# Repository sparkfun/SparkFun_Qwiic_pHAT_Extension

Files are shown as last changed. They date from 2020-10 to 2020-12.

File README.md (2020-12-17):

SparkFun Raspberry Pi 400 Qwiic pHAT Extension
========================================

SparkFun Raspberry Pi 400 Qwiic pHAT Extension (https://www.sparkfun.com/products/17512)

[*SparkFun Raspberry Pi 400 Qwiic pHAT Extension (DEV-17512)*](https://www.sparkfun.com/products/17512)

The SparkFun Qwiic pHAT Extension for the Raspberry Pi 400 provides you with a quick and easy solution to access all of the 400's GPIO, stack your favorite HAT right-side up, or connect a Qwiic-enabled device to the I<sup>2</sup>C bus (GND, 3.3V, SDA, and SCL). Since the Qwiic system allows for daisy-chaining boards with different addresses, you can also stack as many sensors as you’d like to the mounting holes on the pHAT to create a tower of sensing power! 

The Qwiic pHAT Extension connects to the Raspberry Pi 400's GPIO using a 2x20 right angle header and extends out to the edge of the PCB. Two Qwiic connectors are included on each side of the board for easy access to the I<sup>2</sup>C bus. A set of large silicone bumpers have also been included for better stability when connecting the Qwiic pHAT Extension to the Raspberry Pi 400's GPIO port. 

Repository Contents
-------------------

* **/Hardware** - Eagle design files (.brd, .sch)
* **/Production** - Production panel files (.brd)

Documentation
--------------
* **[Qwiic Py](https://github.com/sparkfun/Qwiic_Py)** - Python packages for Qwiic-enabled devices
* **[Hookup Guide](https://learn.sparkfun.com/tutorials/raspberry-pi-400-qwiic-phat-extension-hookup-guide)** - Basic hookup guide

Product Versions
----------------
* [DEV-17512](https://www.sparkfun.com/products/17512)

Version History
---------------
* [v1.0](https://github.com/sparkfun/SparkFun_Qwiic_pHAT_Extension/tree/v1.0) - Initial Release

License Information
-------------------

This product is _**open source**_! 

Please review the LICENSE.md file for license information. 

If you have any questions or concerns on licensing, please contact technical support on our [SparkFun forums](https://forum.sparkfun.com/viewforum.php?f=152).

Distributed as-is; no warranty is given.

- Your friends at SparkFun.

_<COLLABORATION CREDIT>_

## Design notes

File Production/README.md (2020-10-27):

SparkFun <PRODUCT NAME> Production Files
=========================================

These are the production files SparkFun uses for printing PCBs.

License Information
-------------------
This product is open source! 

The hardware is released under [Creative Commons ShareAlike 4.0 International](https://creativecommons.org/licenses/by-sa/4.0/).

Please use, reuse, and modify these files as you see fit. Please maintain attribution to SparkFun Electronics and release anything derivative under the same license.

Distributed as-is; no warranty is given.

- Your friends at SparkFun.

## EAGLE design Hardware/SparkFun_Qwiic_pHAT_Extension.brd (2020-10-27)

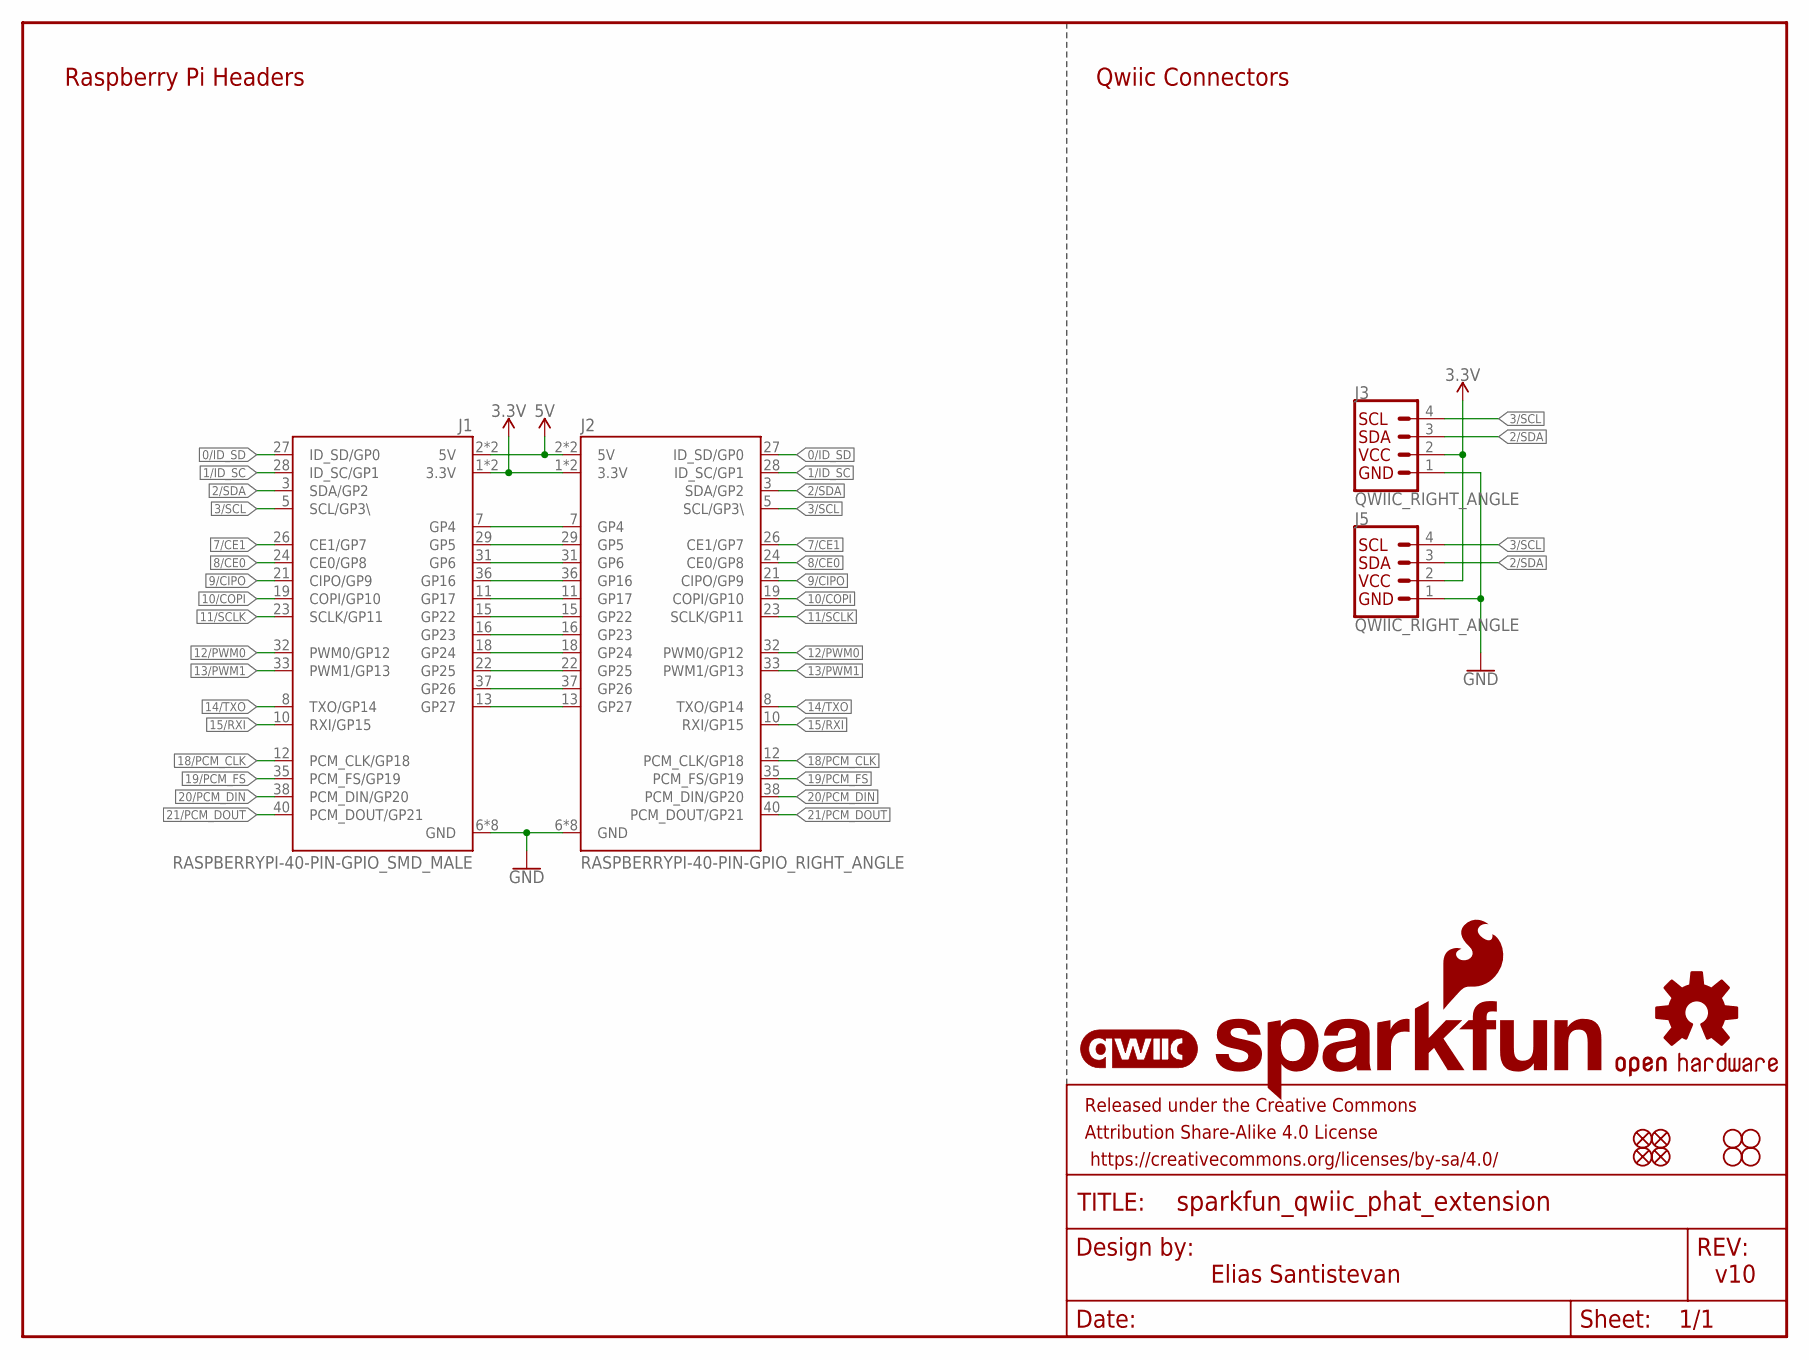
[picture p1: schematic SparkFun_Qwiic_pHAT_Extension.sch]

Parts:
FD1, FD2, FD3, FD4: FIDUCIALUFIDUCIAL; FIDUCIAL-MICRO
FRAME1: FRAME-LETTER; CREATIVE_COMMONS
H1, H2, H3, H4: STAND-OFFTIGHT; STAND-OFF-TIGHT
J1: RASPBERRYPI-40-PIN-GPIO_SMD_MALE; RASPBERRY_PI_HAT_40_PIN_SMD_MALE
J2: RASPBERRYPI-40-PIN-GPIO_RIGHT_ANGLE; 2X20_RIGHT_ANGLE
J3, J5: QWIIC_RIGHT_ANGLE; JST04_1MM_RA
LOGO1: QWIIC_LOGO_5MM; QWIIC_5MM
LOGO2: SFE_LOGO_NAME_FLAME.2_INCH; SFE_LOGO_NAME_FLAME_.2
LOGO3: OSHW-LOGOM; OSHW-LOGO-M

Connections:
0/ID_SD: J1.27 (ID_SD/GP0), J2.27 (ID_SD/GP0)
1/ID_SC: J1.28 (ID_SC/GP1), J2.28 (ID_SC/GP1)
2/SDA: J1.3 (SDA/GP2), J2.3 (SDA/GP2), J3.3, J5.3
3.3V: J1.1 (3.3V), J1.17 (3.3V), J2.1 (3.3V), J2.17 (3.3V), J3.2, J5.2
3/SCL: J1.5 (SCL/GP3\), J2.5 (SCL/GP3\), J3.4, J5.4
5V: J1.2 (5V), J1.4 (5V), J2.2 (5V), J2.4 (5V)
7/CE1: J1.26 (CE1/GP7), J2.26 (CE1/GP7)
8/CE0: J1.24 (CE0/GP8), J2.24 (CE0/GP8)
9/CIPO: J1.21 (CIPO/GP9), J2.21 (CIPO/GP9)
10/COPI: J1.19 (COPI/GP10), J2.19 (COPI/GP10)
11/SCLK: J1.23 (SCLK/GP11), J2.23 (SCLK/GP11)
12/PWM0: J1.32 (PWM0/GP12), J2.32 (PWM0/GP12)
13/PWM1: J1.33 (PWM1/GP13), J2.33 (PWM1/GP13)
14/TXO: J1.8 (TXO/GP14), J2.8 (TXO/GP14)
15/RXI: J1.10 (RXI/GP15), J2.10 (RXI/GP15)
18/PCM_CLK: J1.12 (PCM_CLK/GP18), J2.12 (PCM_CLK/GP18)
19/PCM_FS: J1.35 (PCM_FS/GP19), J2.35 (PCM_FS/GP19)
20/PCM_DIN: J1.38 (PCM_DIN/GP20), J2.38 (PCM_DIN/GP20)
21/PCM_DOUT: J1.40 (PCM_DOUT/GP21), J2.40 (PCM_DOUT/GP21)
GND: J1.6 (GND), J1.9 (GND), J1.14 (GND), J1.20 (GND), J1.25 (GND), J1.30 (GND), J1.34 (GND), J1.39 (GND), J2.6 (GND), J2.9 (GND), J2.14 (GND), J2.20 (GND), J2.25 (GND), J2.30 (GND), J2.34 (GND), J2.39 (GND), J3.1, J5.1
GP4: J1.7 (GP4), J2.7 (GP4)
GP5: J1.29 (GP5), J2.29 (GP5)
GP6: J1.31 (GP6), J2.31 (GP6)
GP16: J1.36 (GP16), J2.36 (GP16)
GP17: J1.11 (GP17), J2.11 (GP17)
GP22: J1.15 (GP22), J2.15 (GP22)
GP23: J1.16 (GP23), J2.16 (GP23)
GP24: J1.18 (GP24), J2.18 (GP24)
GP25: J1.22 (GP25), J2.22 (GP25)
GP26: J1.37 (GP26), J2.37 (GP26)
GP27: J1.13 (GP27), J2.13 (GP27)

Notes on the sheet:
Elias Santistevan
v10
Qwiic Connectors
Raspberry Pi Headers

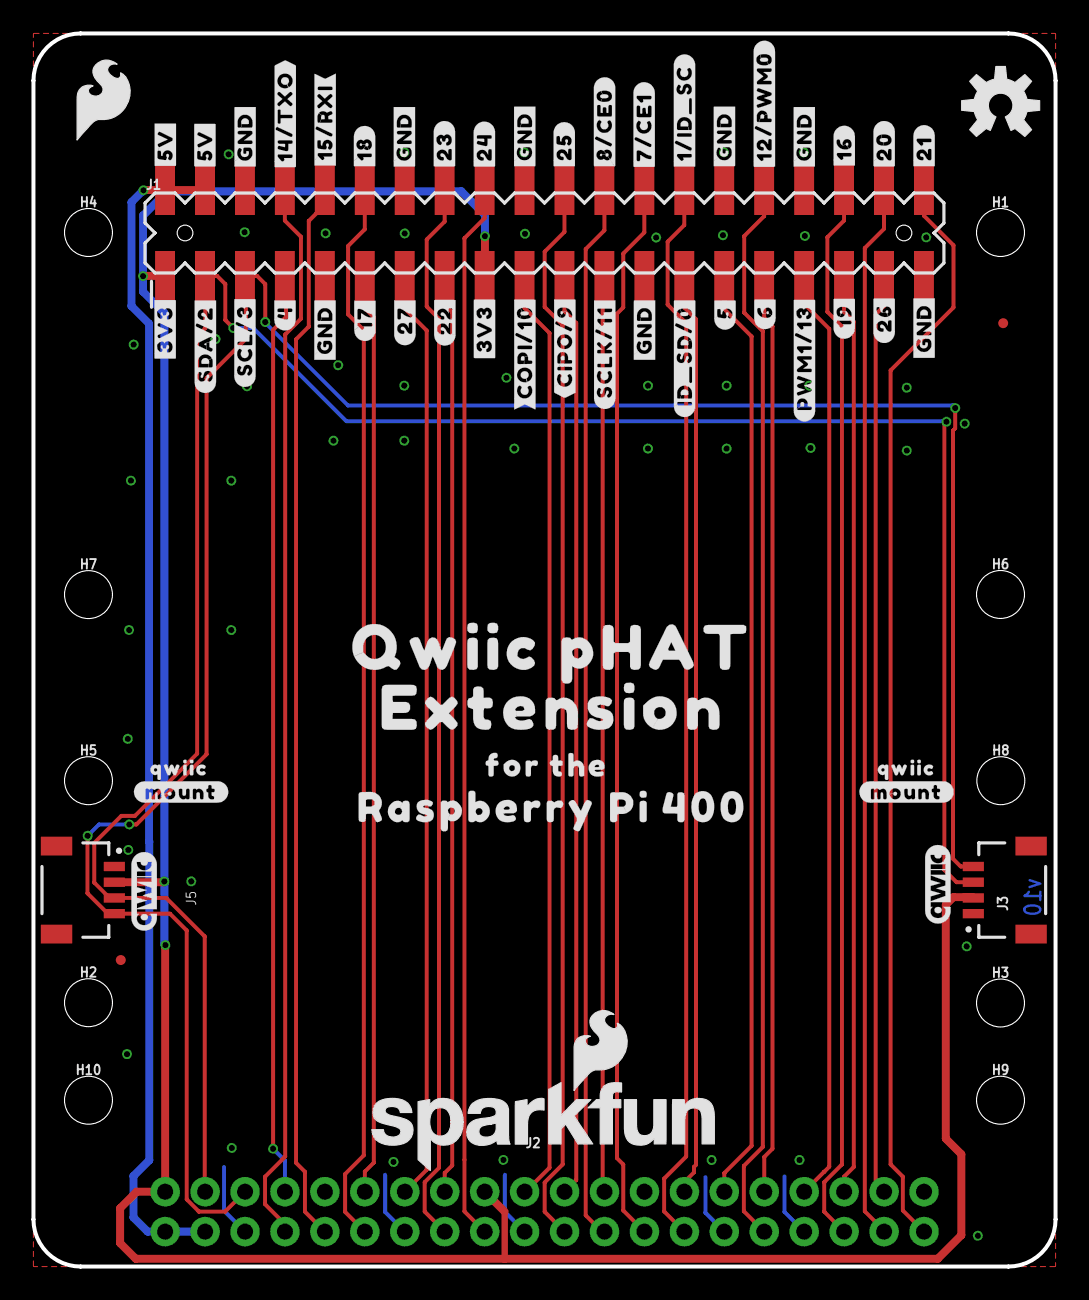
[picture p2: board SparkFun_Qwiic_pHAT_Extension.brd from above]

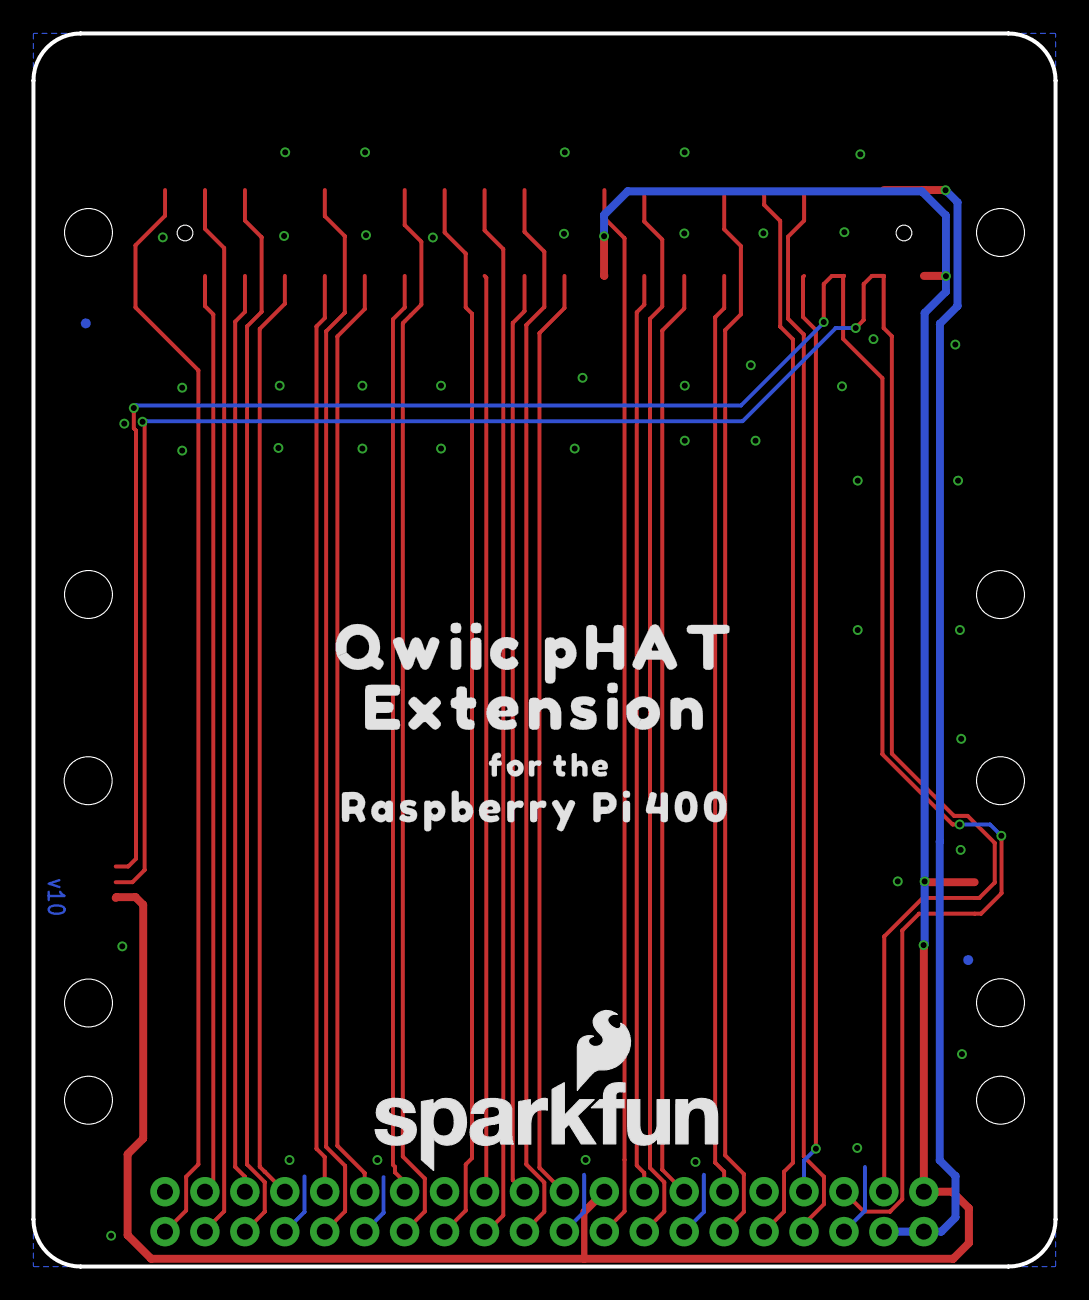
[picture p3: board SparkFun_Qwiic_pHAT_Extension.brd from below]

Board: 2 copper layers, 65.0 x 78.4 mm, 77 parts (7 on the bottom side), 31 nets.

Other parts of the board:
H5, H6, H7, H8, H9, H10: STAND-OFFTIGHT; STAND-OFF-TIGHT
LOGO4: QWIIC_LOGO_5MM; QWIIC_5MM
LOGO5: SFE_LOGO_NAME_FLAME.2_INCH; SFE_LOGO_NAME_FLAME_.2
U$1: #SDA#2#4
U$2: #SCL#3#4
U$3, U$13: FOR_THE40034
U$4, U$5: #3V3#0
U$6: #4#4
U$7: #5#28
U$8, U$9: #5V#28
U$10: #6#28
U$11: #7#CE1#29
U$12: #8#CE0#29
U$14: #SCLK#11#28
U$15: #ID_SD#0#28
U$16: #12#PWM0#29
U$17: #PWM1#13#28
U$18: #14#TXO#29
U$19: #15#RXI#29
U$20: #16#29
U$21: #17#5
U$22: #18#29
U$23: #19#28
U$24: #20#29
U$25: #21#29
U$26: #22#28
U$27: #23#29
U$28: #24#29
U$29: #25#29
U$30: #26#28
U$31: #27#18
U$32, U$33, U$34, U$35, U$36, U$37, U$38, U$39: #GND#28
U$40: #1#ID_SC#29
U$51: #CIPO#9#28
U$52: #COPI#10#28
U$75, U$89: QWIIC_PHAT31
U$76, U$90: EXTENSION32
U$81: SFE_LOGO_FLAME_.2
U$82, U$83: #MOUNT#29
U$84, U$85: QWIIC30
U$86, U$91: RASPBERRY_PI_40033

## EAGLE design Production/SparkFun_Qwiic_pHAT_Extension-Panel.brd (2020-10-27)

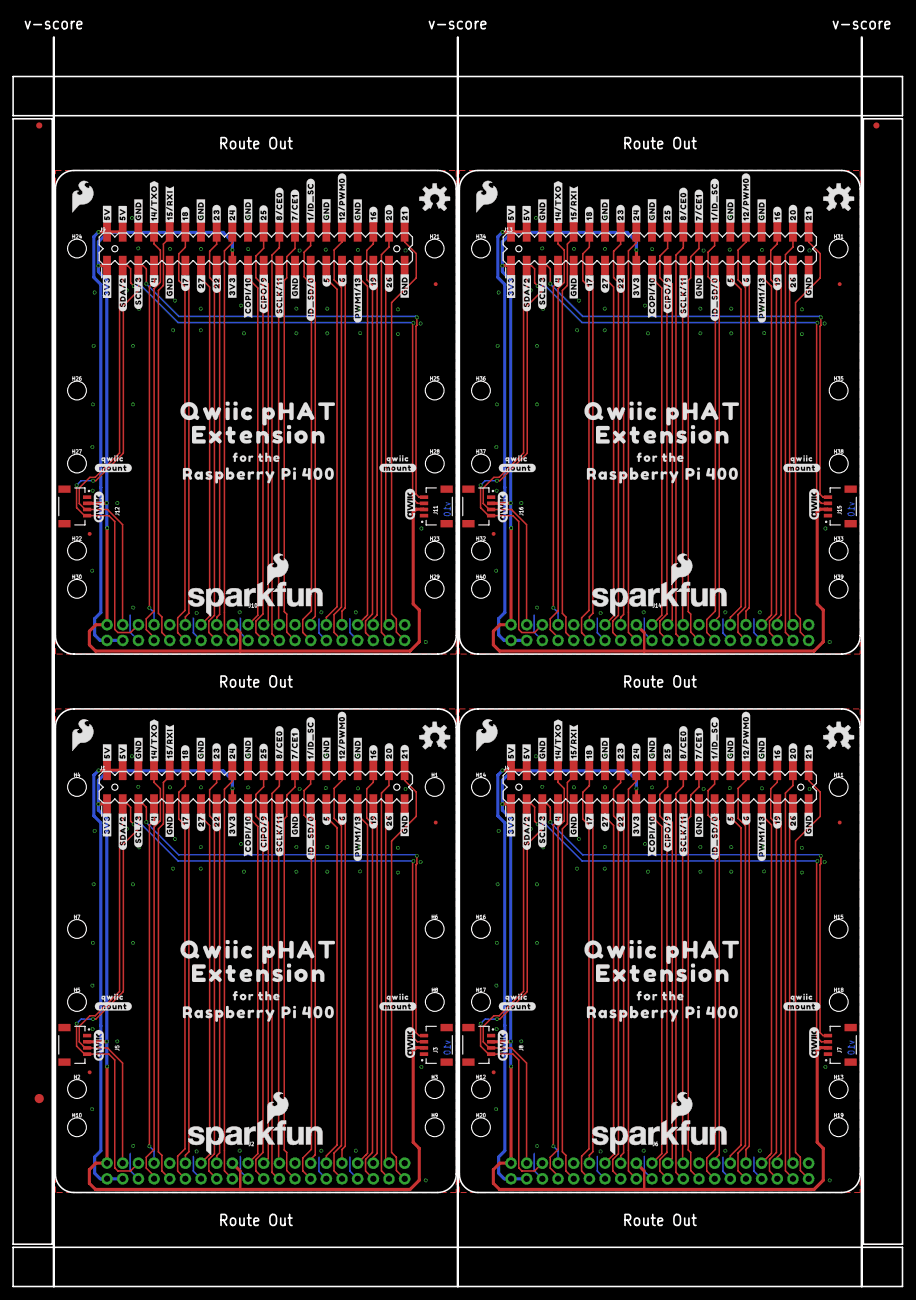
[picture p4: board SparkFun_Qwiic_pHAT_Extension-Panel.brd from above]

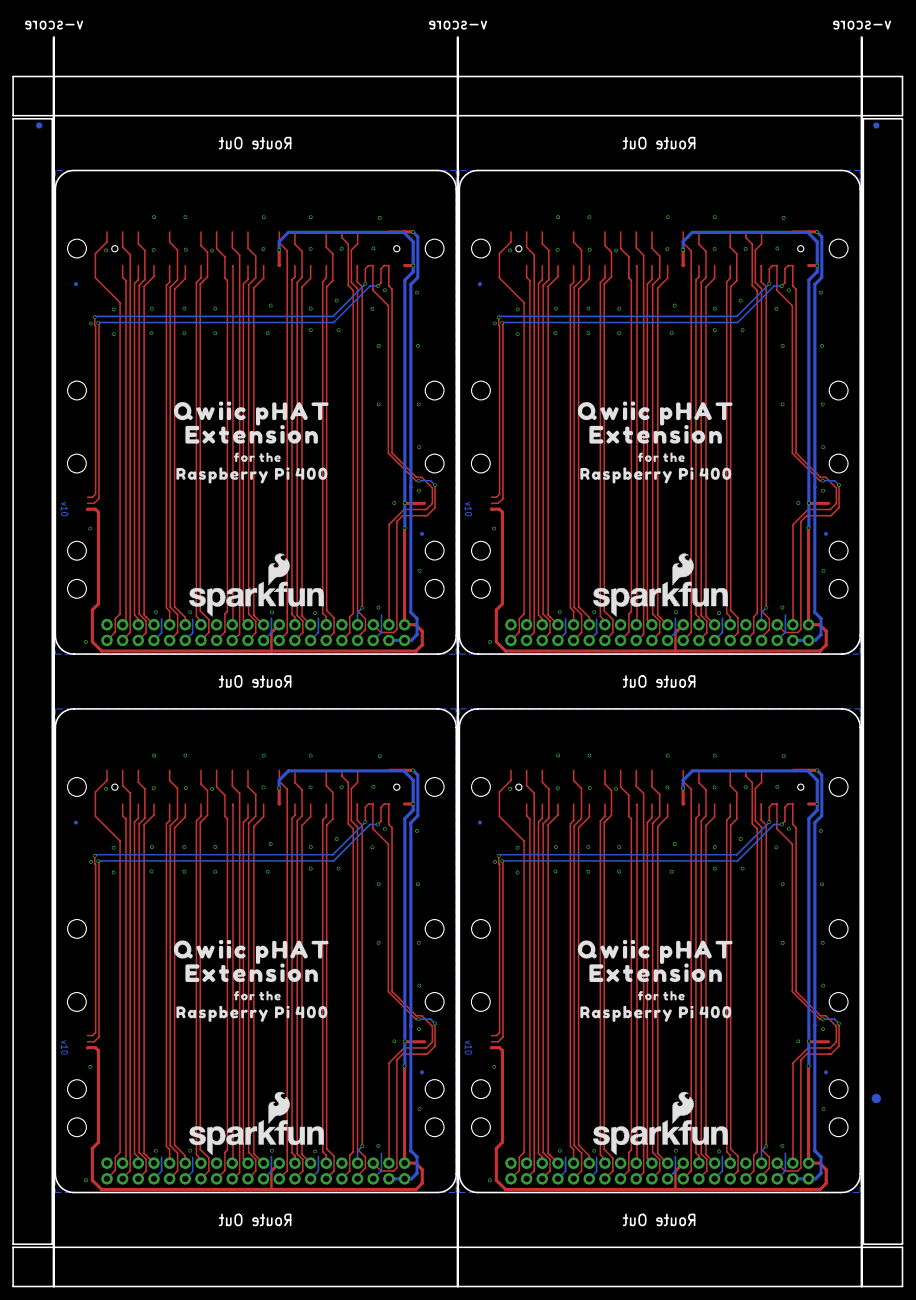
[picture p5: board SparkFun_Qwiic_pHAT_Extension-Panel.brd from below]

Board: 2 copper layers, 144.2 x 202.6 mm, 310 parts (31 on the bottom side), 124 nets.

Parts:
E$1, E$2, E$3, E$4: FIDUCIAL-1X2
E$5, E$6: FIDUCIAL-1.5X3
FD1, FD2, FD3, FD4, FD5, FD6, FD7, FD8, FD9, FD10, FD11, FD12, FD13, FD14, FD15, FD16: FIDUCIALUFIDUCIAL; FIDUCIAL-MICRO
H1, H2, H3, H4, H5, H6, H7, H8, H9, H10, H11, H12, H13, H14, H15, H16, H17, H18, H19, H20, H21, H22, H23, H24, H25, H26, H27, H28, H29, H30, H31, H32, H33, H34, H35, H36, H37, H38, H39, H40: STAND-OFFTIGHT; STAND-OFF-TIGHT
J1, J4, J9, J13: RASPBERRYPI-40-PIN-GPIO_SMD_MALE; RASPBERRY_PI_HAT_40_PIN_SMD_MALE
J2, J6, J10, J14: RASPBERRYPI-40-PIN-GPIO_RIGHT_ANGLE; 2X20_RIGHT_ANGLE
J3, J5, J7, J8, J11, J12, J15, J16: QWIIC_RIGHT_ANGLE; JST04_1MM_RA
LOGO1, LOGO4, LOGO6, LOGO9, LOGO11, LOGO14, LOGO16, LOGO19: QWIIC_LOGO_5MM; QWIIC_5MM
LOGO2, LOGO5, LOGO7, LOGO10, LOGO12, LOGO15, LOGO17, LOGO20: SFE_LOGO_NAME_FLAME.2_INCH; SFE_LOGO_NAME_FLAME_.2
LOGO3, LOGO8, LOGO13, LOGO18: OSHW-LOGOM; OSHW-LOGO-M
U$1, U$74, U$138, U$191: #SDA#2#4
U$2, U$77, U$139, U$192: #SCL#3#4
U$3, U$13, U$105, U$106, U$158, U$159, U$211, U$212: FOR_THE40034
U$4, U$5, U$41, U$42, U$107, U$108, U$160, U$161: #3V3#0
U$6, U$43, U$109, U$162: #4#4
U$7, U$44, U$110, U$163: #5#28
U$8, U$9, U$45, U$46, U$111, U$112, U$164, U$165: #5V#28
U$10, U$47, U$113, U$166: #6#28
U$11, U$48, U$114, U$167: #7#CE1#29
U$12, U$49, U$115, U$168: #8#CE0#29
U$14, U$78, U$140, U$193: #SCLK#11#28
U$15, U$79, U$141, U$194: #ID_SD#0#28
U$16, U$50, U$116, U$169: #12#PWM0#29
U$17, U$80, U$142, U$195: #PWM1#13#28
U$18, U$97, U$150, U$203: #14#TXO#29
U$19, U$98, U$151, U$204: #15#RXI#29
U$20, U$53, U$117, U$170: #16#29
U$21, U$54, U$118, U$171: #17#5
U$22, U$55, U$119, U$172: #18#29
U$23, U$56, U$120, U$173: #19#28
U$24, U$57, U$121, U$174: #20#29
U$25, U$58, U$122, U$175: #21#29
U$26, U$59, U$123, U$176: #22#28
U$27, U$60, U$124, U$177: #23#29
U$28, U$61, U$125, U$178: #24#29
U$29, U$62, U$126, U$179: #25#29
U$30, U$63, U$127, U$180: #26#28
U$31, U$64, U$128, U$181: #27#18
U$32, U$33, U$34, U$35, U$36, U$37, U$38, U$39, U$65, U$66, U$67, U$68, U$69, U$70, U$71, U$72, U$129, U$130, U$131, U$132, U$133, U$134, U$135, U$136, U$182, U$183, U$184, U$185, U$186, U$187, U$188, U$189: #GND#28
U$40, U$73, U$137, U$190: #1#ID_SC#29
U$51, U$88, U$144, U$197: #CIPO#9#28
U$52, U$92, U$145, U$198: #COPI#10#28
U$75, U$89, U$99, U$102, U$152, U$155, U$205, U$208: QWIIC_PHAT31
U$76, U$90, U$100, U$103, U$153, U$156, U$206, U$209: EXTENSION32
U$81, U$87, U$143, U$196: SFE_LOGO_FLAME_.2
U$82, U$83, U$93, U$94, U$146, U$147, U$199, U$200: #MOUNT#29
U$84, U$85, U$95, U$96, U$148, U$149, U$201, U$202: QWIIC30
U$86, U$91, U$101, U$104, U$154, U$157, U$207, U$210: RASPBERRY_PI_40033

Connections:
0/ID_SD: J1.27, J2.27
0/ID_SD1: J4.27, J6.27
0/ID_SD2: J9.27, J10.27
0/ID_SD3: J13.27, J14.27
1/ID_SC: J1.28, J2.28
1/ID_SC1: J4.28, J6.28
1/ID_SC2: J9.28, J10.28
1/ID_SC3: J13.28, J14.28
2/SDA: J1.3, J2.3, J3.3, J5.3
2/SDA1: J4.3, J6.3, J7.3, J8.3
2/SDA2: J9.3, J10.3, J11.3, J12.3
2/SDA3: J13.3, J14.3, J15.3, J16.3
3.3V: J1.1, J1.17, J2.1, J2.17, J3.2, J5.2
3.3V1: J4.1, J4.17, J6.1, J6.17, J7.2, J8.2
3.3V2: J9.1, J9.17, J10.1, J10.17, J11.2, J12.2
3.3V3: J13.1, J13.17, J14.1, J14.17, J15.2, J16.2
3/SCL: J1.5, J2.5, J3.4, J5.4
3/SCL1: J4.5, J6.5, J7.4, J8.4
3/SCL2: J9.5, J10.5, J11.4, J12.4
3/SCL3: J13.5, J14.5, J15.4, J16.4
5V: J1.2, J1.4, J2.2, J2.4
5V1: J4.2, J4.4, J6.2, J6.4
5V2: J9.2, J9.4, J10.2, J10.4
5V3: J13.2, J13.4, J14.2, J14.4
7/CE1: J1.26, J2.26
7/CE2: J4.26, J6.26
7/CE3: J9.26, J10.26
7/CE4: J13.26, J14.26
8/CE0: J1.24, J2.24
8/CE1: J4.24, J6.24
8/CE2: J9.24, J10.24
8/CE3: J13.24, J14.24
9/CIPO: J1.21, J2.21
9/CIPO1: J4.21, J6.21
9/CIPO2: J9.21, J10.21
9/CIPO3: J13.21, J14.21
10/COPI: J1.19, J2.19
10/COPI1: J4.19, J6.19
10/COPI2: J9.19, J10.19
10/COPI3: J13.19, J14.19
11/SCLK: J1.23, J2.23
11/SCLK1: J4.23, J6.23
11/SCLK2: J9.23, J10.23
11/SCLK3: J13.23, J14.23
12/PWM0: J1.32, J2.32
12/PWM1: J4.32, J6.32
12/PWM2: J9.32, J10.32
12/PWM3: J13.32, J14.32
13/PWM1: J1.33, J2.33
13/PWM2: J4.33, J6.33
13/PWM3: J9.33, J10.33
13/PWM4: J13.33, J14.33
14/TXO: J1.8, J2.8
14/TXO1: J4.8, J6.8
14/TXO2: J9.8, J10.8
14/TXO3: J13.8, J14.8
15/RXI: J1.10, J2.10
15/RXI1: J4.10, J6.10
15/RXI2: J9.10, J10.10
15/RXI3: J13.10, J14.10
18/PCM_CLK: J1.12, J2.12
18/PCM_CLK1: J4.12, J6.12
18/PCM_CLK2: J9.12, J10.12
18/PCM_CLK3: J13.12, J14.12
19/PCM_FS: J1.35, J2.35
19/PCM_FS1: J4.35, J6.35
19/PCM_FS2: J9.35, J10.35
19/PCM_FS3: J13.35, J14.35
20/PCM_DIN: J1.38, J2.38
20/PCM_DIN1: J4.38, J6.38
20/PCM_DIN2: J9.38, J10.38
20/PCM_DIN3: J13.38, J14.38
21/PCM_DOUT: J1.40, J2.40
21/PCM_DOUT1: J4.40, J6.40
21/PCM_DOUT2: J9.40, J10.40
21/PCM_DOUT3: J13.40, J14.40
GND: J1.6, J1.9, J1.14, J1.20, J1.25, J1.30, J1.34, J1.39, J2.6, J2.9, J2.14, J2.20, J2.25, J2.30, J2.34, J2.39, J3.1, J5.1
GND1: J4.6, J4.9, J4.14, J4.20, J4.25, J4.30, J4.34, J4.39, J6.6, J6.9, J6.14, J6.20, J6.25, J6.30, J6.34, J6.39, J7.1, J8.1
GND2: J9.6, J9.9, J9.14, J9.20, J9.25, J9.30, J9.34, J9.39, J10.6, J10.9, J10.14, J10.20, J10.25, J10.30, J10.34, J10.39, J11.1, J12.1
GND3: J13.6, J13.9, J13.14, J13.20, J13.25, J13.30, J13.34, J13.39, J14.6, J14.9, J14.14, J14.20, J14.25, J14.30, J14.34, J14.39, J15.1, J16.1
GP1: J4.7, J6.7
GP2: J4.29, J6.29
GP3: J4.31, J6.31
GP4: J1.7, J2.7
GP5: J1.29, J2.29
GP6: J1.31, J2.31
GP7: J4.36, J6.36
GP8: J4.11, J6.11
GP9: J4.15, J6.15
GP10: J4.16, J6.16
GP11: J4.18, J6.18
GP12: J4.22, J6.22
GP13: J4.37, J6.37
GP14: J4.13, J6.13
GP15: J9.7, J10.7
GP16: J1.36, J2.36
GP17: J1.11, J2.11
GP18: J9.29, J10.29
GP19: J9.31, J10.31
GP20: J9.36, J10.36
GP21: J9.11, J10.11
GP22: J1.15, J2.15
GP23: J1.16, J2.16
GP24: J1.18, J2.18
GP25: J1.22, J2.22
GP26: J1.37, J2.37
GP27: J1.13, J2.13
GP28: J9.15, J10.15
GP29: J9.16, J10.16
GP30: J9.18, J10.18
GP31: J9.22, J10.22
GP32: J9.37, J10.37
GP33: J9.13, J10.13
GP34: J13.7, J14.7
GP35: J13.29, J14.29
GP36: J13.31, J14.31
GP37: J13.36, J14.36
GP38: J13.11, J14.11
GP39: J13.15, J14.15
GP40: J13.16, J14.16
GP41: J13.18, J14.18
GP42: J13.22, J14.22
GP43: J13.37, J14.37
GP44: J13.13, J14.13

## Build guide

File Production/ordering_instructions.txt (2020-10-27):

panel size, 145x181mm
PCB thickness, 1.6mm
number of layers, 2
soldermask color, Red
silkscreen color, White
oz copper, 1oz
finish, HASL lead free
stencils, top
pcs per panel, 4
min trace width, 0.2540mm / 0.0100in
min drill size, 0.3810mm / 0.0150in

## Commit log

2020-10-23 Updates symbol which required an entire reroute of the board
    * Adds "qwiic mount" silk
    * moves Qwiic connector "lower" on the board to align with standoffs
    * Adds standoffs for micro-hats
    [phatdapter.brd, phatdapter.sch]
2020-10-23 Swaps the rows of PTH holes on the right angle connector
    [phatdapter.brd, phatdapter.sch]
2020-10-26 Adds name to board
    [phatdapter.brd, phatdapter.sch]
2020-10-26 Removes labels from underneath the board
    [phatdapter.brd]
2020-10-26 Adds "for the" silk, shrinks SparkFun logo
    [phatdapter.brd]
2020-10-26 Adds better measures
    [phatdapter.brd]
2020-10-26 Removes extra Tdocu lines
    [phatdapter.brd]
2020-10-26 Adds a single GND via
    [phatdapter.brd]
2020-10-27 Moves standoffs for Qwiic mount because it would have interfered with micro Raspberry hats
    [phatdapter.brd]
2020-10-27 Updates the names of the eagle files to correct name, adds license, readme, etc
    [SparkFun_Qwiic_pHAT_Extension.brd, SparkFun_Qwiic_pHAT_Extension.sch]
2020-10-27 Fixes PWM net names, fixes measures to account for moved stand offs
    [SparkFun_Qwiic_pHAT_Extension.brd, SparkFun_Qwiic_pHAT_Extension.sch]
2020-10-27 Adds 2x2 production panel
    [SparkFun_Qwiic_pHAT_Extension-Panel.GBL, SparkFun_Qwiic_pHAT_Extension-Panel.GBO, SparkFun_Qwiic_pHAT_Extension-Panel.GBP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]
2020-10-27 Moves fiducials on the panel to the attached portions of the panel frame
    [SparkFun_Qwiic_pHAT_Extension-Panel.brd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]

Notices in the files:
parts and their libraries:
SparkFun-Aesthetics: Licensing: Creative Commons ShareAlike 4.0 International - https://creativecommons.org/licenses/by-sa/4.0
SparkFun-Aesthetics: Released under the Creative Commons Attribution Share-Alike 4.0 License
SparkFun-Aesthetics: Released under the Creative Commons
